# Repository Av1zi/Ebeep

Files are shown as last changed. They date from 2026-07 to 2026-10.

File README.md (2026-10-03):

# Ebeep





Two handheld wireless devices that can message each other and play games, built as a personal gift.

> **E** for eInk. **Beep** for beeper

---

## Project Showcase

### 3d render
https://github.com/user-attachments/assets/a6d2f698-0696-4dca-adf1-06d3810ce39c

### walkthrough
https://github.com/user-attachments/assets/030f00d7-5b2a-4592-a6ae-74eca7de7010

---

## Features

- **Messaging** - 3-button scrollable alphabet, double-space to send
- **Games** - TicTacToe, Connect 4, and Blackjack, all multiplayer over MQTT
- **E-Ink display** - 2.9" screen and low power consumption
- **Battery powered** - LiPo with USB-C charging, percentage always visible
- **Deep sleep** - wakes on a timer or button press to maximise battery life
- **Long range** - talks over WiFi/MQTT, so both devices work from anywhere with an internet connection

---

## Hardware

| Component | Part |
|---|---|
| Microcontroller | Seeed XIAO ESP32-C6 |
| Display | WeAct 2.9" eInk |
| Battery | 3.7V LiPo, 3000mAh |
| Buttons | 3× low profile mechanical keyboard switches |
| Case | ~76g PLA filament <br> 4× M4 heated inserts <br> 4× M4×25 screws |
| Other | 2× 200kΩ resistors (voltage divider for battery sensing) <br> 5×7cm perfboard |

---

## How It Works

### Communication
Both devices connect to WiFi and talk through a private MQTT broker. Each device subscribes to its own topic and publishes to the other's.

### WiFi Setup
On first boot the device creates a hotspot (`Ebeep_1_config` or `Ebeep_2_config`). Connect to it from any phone and a setup page pops up automatically - pick your network, enter the password, done. Credentials are saved to flash and never asked for again unless the connection fails. see walkthrough below:

https://github.com/user-attachments/assets/75ae72dc-5833-4c83-8c6c-1c9a049145ae

### Typing Interface
- **Left / Right** - scroll through characters (`SPC A B C ... Z . ! ? <3`)
- **Select** - confirm the current character
- **Two spaces in a row** - send the message
- **DEL on empty** - exit compose

### Games

- **TicTacToe** - classic 3×3, first message sent starts the match
- **Connect 4** - 7×6 grid, gravity-based drop
- **Blackjack** - single-player, full ruleset with split, double, and a soft-17 dealer

### Power Management
The device spends most of its time in deep sleep, waking every 30 seconds to check for messages. Night hours (00:00–08:00) and low battery stretch that to 2 minutes. Any button press or incoming message triggers a 10-minute active window before it goes back to sleep.

---

## PCB

A custom PCB has been fully designed and routed in KiCad to replace the hand-wired perfboard build. It's not ordered/fabricated yet, so the current build instructions below are still perfboard based (the PCB is a planned upgrade for a future revision.)

> [!WARNING]
> The PCB has not been fitted or tested against the STL case files in this repo. If you order it, expect to redesign the case (or at least the mounting points) to fit. it is **not** a drop-in replacement yet.

---

## Building Your Own

### Electrical Diagram


### Building Instructions
1. 3D print the files from the `CAD` folder
2. Solder everything onto the perfboard following the electrical diagram above
3. Flash the code (see **Setting Up the Code** below) and test before closing the case
4. Fit the components into the case & add double-sided tape under the battery to secure it
5. Press in the 4× M4 heated inserts, then screw the case shut with the M4 screws

### Setting Up the Code
1. Change `DEVICE_NUM` to `1` on one device and `2` on the other
2. Copy `include/secret.example.h` to `include/secret.h` and fill in your MQTT broker credentials (`secret.h` is gitignored so it stays private)
3. Upload via PlatformIO - the `huge_app.csv` partition scheme is required
4. On first boot, connect to the config hotspot (`Ebeep_1_config` or `Ebeep_2_config`) and enter your WiFi credentials

---

## License

GPL 3.0 - Do whatever you want with it, just keep it open source as well.

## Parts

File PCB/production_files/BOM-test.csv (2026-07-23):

Comment | Designator | Footprint | LCSC | Quantity
100nF | C1 | C_0603_1608Metric |  | 1
200K | R1 | R_0603_1608Metric |  | 1
WeAct 2.9" ePaper | Epapers1 | Molex_PicoBlade_53261-0871_1x08-1MP_P1.25mm_Horizontal |  | 1
Conn_01x02 | JST-PH-2pin1 | JST_PH_S2B-PH-K_1x02_P2.00mm_Horizontal |  | 1
100nF | C2 | C_0603_1608Metric |  | 1
200K | R2 | R_0603_1608Metric |  | 1

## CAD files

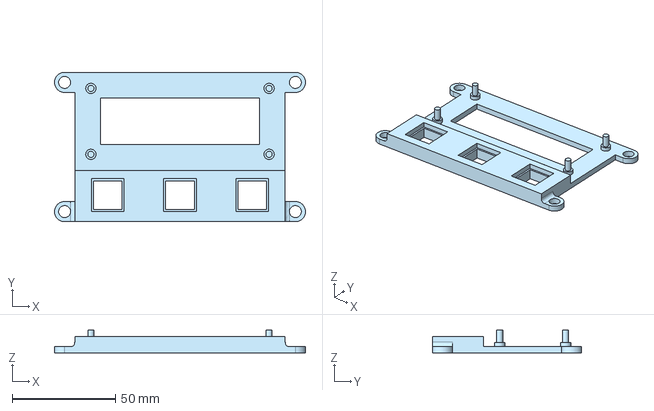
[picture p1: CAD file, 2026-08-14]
CAD/V2 - Top.step
121.4 x 72.3 x 11.0 mm

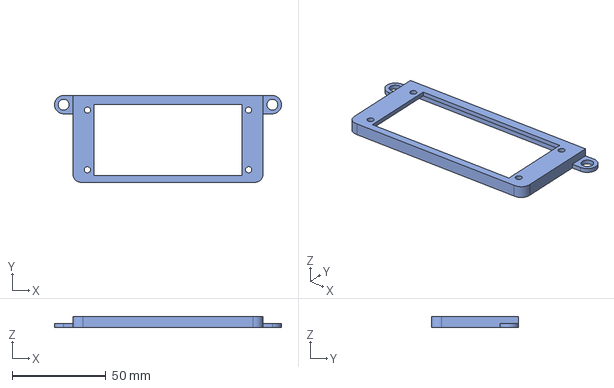
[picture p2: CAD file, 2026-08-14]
CAD/V2 - ScreenCover.step
121.4 x 46.5 x 5.69 mm

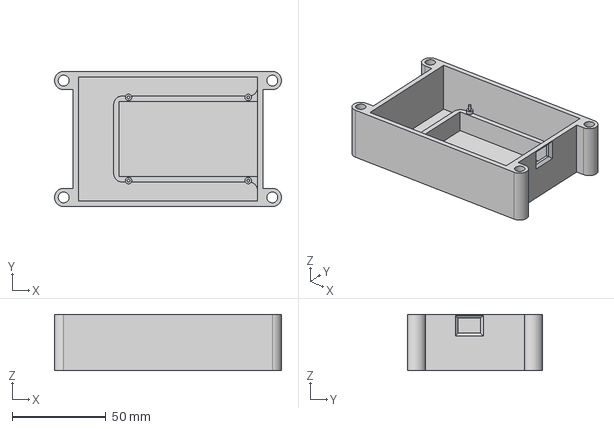
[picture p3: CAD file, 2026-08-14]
CAD/V2 - housing.step
121.4 x 72.3 x 30.0 mm

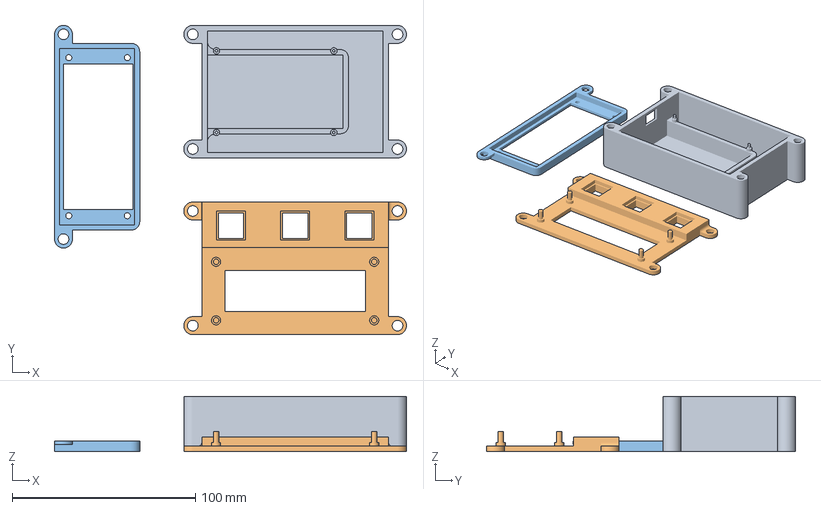
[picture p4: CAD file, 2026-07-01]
CAD/Ebeep V2.3mf
191.9 x 168.6 x 30.0 mm
Ebeep V2 - housing.stl
Ebeep V2 - Top.stl
Ebeep V2 - ScreenCover.stl

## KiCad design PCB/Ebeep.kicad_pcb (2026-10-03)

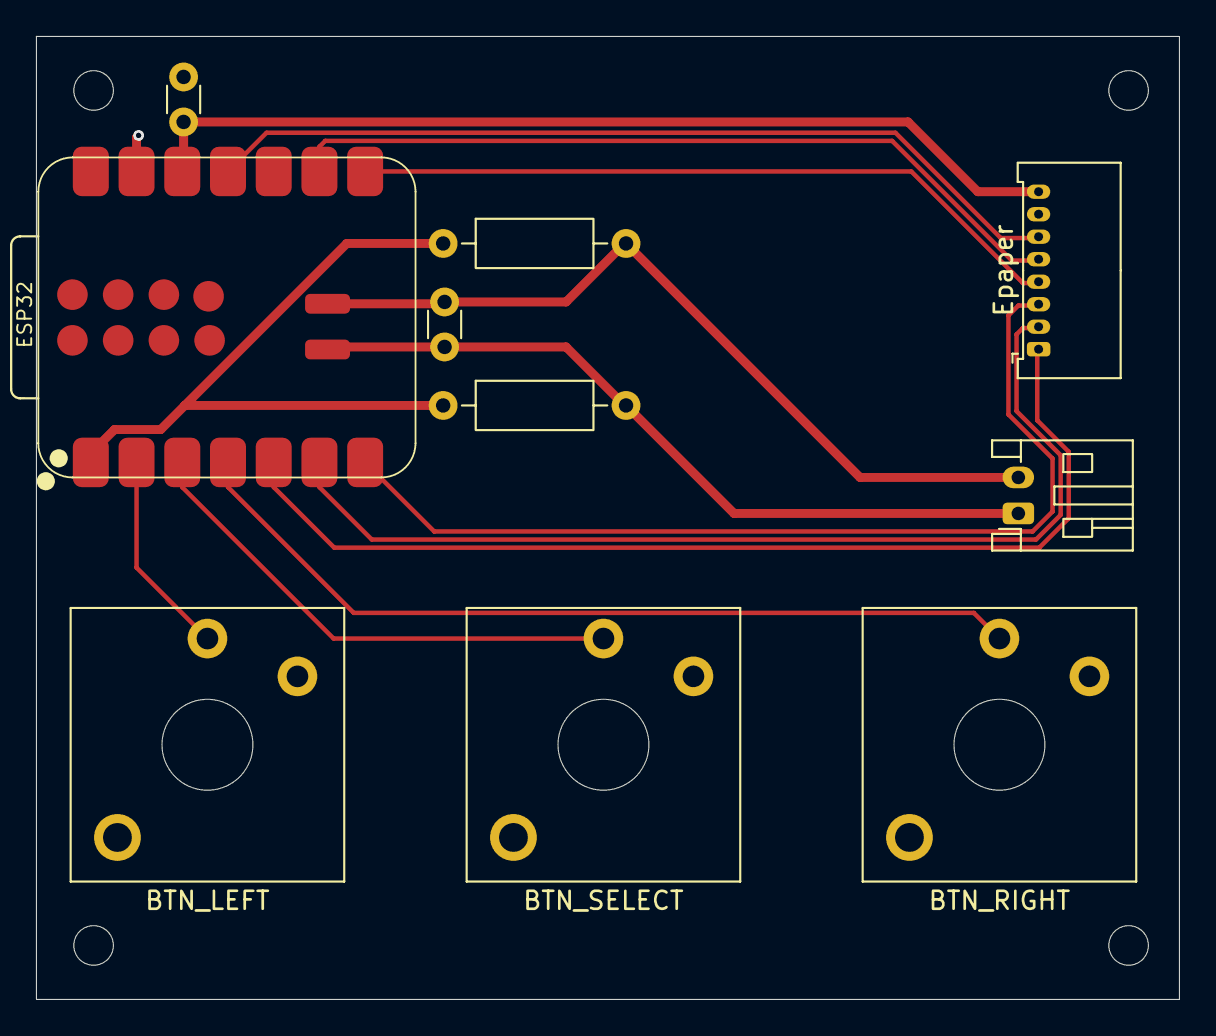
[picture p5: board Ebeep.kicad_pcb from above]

Board: 2 copper layers, 63.5 x 53.5 mm, 10 parts (0 on the bottom side), 14 nets.

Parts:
BTN_LEFT: SW_Push; SW_Kailh_Choc_V2_1.00u
BTN_RIGHT: SW_Push; SW_Kailh_Choc_V2_1.00u
BTN_SELECT: SW_Push; SW_Kailh_Choc_V2_1.00u
C1, C2: 100nF; C_Disc_D3.0mm_W1.6mm_P2.50mm
ESP32: XIAO-ESP32-C6-SMD
Epaper: WeAct 2.9" ePaper; Molex_PicoBlade_53048-0810_1x08_P1.25mm_Horizontal
JST-PH-2pin1: Conn_01x02; JST_PH_S2B-PH-K_1x02_P2.00mm_Horizontal
R1, R2: 200K; R_Axial_DIN0207_L6.3mm_D2.5mm_P10.16mm_Horizontal

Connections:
/+BATT: C1.1, ESP32.23 (VBAT), JST-PH-2pin1.1, R1.2
/-BATT: C1.2, ESP32.24 (GND), JST-PH-2pin1.2, R2.2
/BUSY: ESP32.5 (D4), Epaper.1
/CS: ESP32.8 (D7), Epaper.4
/D/C: ESP32.7 (D6), Epaper.3
/GND: BTN_LEFT.2, BTN_RIGHT.2, BTN_SELECT.2, C2.1, ESP32.13 (GND), Epaper.7
/RES: ESP32.6 (D5), Epaper.2
/SCL: ESP32.9 (D8), Epaper.5
/SDA: ESP32.11 (D10), Epaper.6
/VCC: C2.2, ESP32.12 (3V3_OUT), Epaper.8
unnamed: ESP32.1 (D0), R1.1, R2.1
unnamed: BTN_LEFT.1, ESP32.2 (D1)
unnamed: BTN_SELECT.1, ESP32.3 (D2)
unnamed: BTN_RIGHT.1, ESP32.4 (D3)

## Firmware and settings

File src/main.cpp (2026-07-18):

#include <Arduino.h>
#include <SPI.h>
#include <GxEPD2_BW.h>
#include <Fonts/FreeMonoBold9pt7b.h>
#include <Fonts/FreeMonoBold12pt7b.h>
#include <Fonts/FreeMonoBold24pt7b.h>
#include <WiFiManager.h>
#include <WiFiClientSecure.h>
#include <PubSubClient.h>

#include "config.h"

// ═══════════════════════════════════════════════════════════════
//  CODE INJECTION  (order matters)
// ═══════════════════════════════════════════════════════════════

#include "display_utils.h"
#include "icons.h"
#include "TicTacToeState.h"
#include "Connect4State.h"
#include "BlackjackState.h"
#include "HomeState.h"
#include "InboxState.h"
#include "ComposeState.h"
#include "SentState.h"
#include "GamesState.h"
#include "WifiState.h"
#include "Callbacks.h"

// ═══════════════════════════════════════════════════════════════
//  Functions
// ═══════════════════════════════════════════════════════════════

WiFiManager wm;
unsigned long lastReconnectAttempt = 0;
bool lastWifiState = false;
bool lastMqttState = false;

void connectWifi(){
  wm.setConfigPortalTimeout(0);  // portal never times out
  if (sizeof(HOTSPOT_PASSWORD) > 1) {
    wm.autoConnect(AP_NAME, AP_password);
  } else {
    wm.autoConnect(AP_NAME);
  }
  while (WiFi.status() != WL_CONNECTED) delay(100);
  Serial.println("WiFi connected");
  lastWifiState = true;
}

// build once instead of allocating a String on every single reconnect attempt.
static char INBOX_TOPIC[24] = "";
static char GAMES_TOPIC[24] = "";

bool connectMQTT(){
  if (INBOX_TOPIC[0] == '\0') {
    snprintf(INBOX_TOPIC, sizeof(INBOX_TOPIC), "%s/inbox", BEEPER_ID);
    snprintf(GAMES_TOPIC, sizeof(GAMES_TOPIC), "%s/games", BEEPER_ID);
  }
  Serial.print("MQTT connect... ");
  if (mqttClient.connect(BEEPER_ID, MQTT_USERNAME_STR, MQTT_PASSWORD_STR)) {
    Serial.println("OK");
    mqttClient.subscribe(INBOX_TOPIC);
    mqttClient.subscribe(GAMES_TOPIC);
    lastMqttState = true;
    return true;
  } else {
    Serial.printf("failed rc=%d\n", mqttClient.state());
    return false;
  }
}

// ═══════════════════════════════════════════════════════════════
//  SETUP
// ═══════════════════════════════════════════════════════════════
void setup() {
  Serial.begin(115200);
  delay(2000);
  Serial.println("=== Ebeep Boot ===");
  currentState = STATE_WIFI;
  needRefresh  = true;

  pinMode(EPD_CS,   OUTPUT);
  pinMode(EPD_DC,   OUTPUT);
  pinMode(EPD_RST,  OUTPUT);
  pinMode(EPD_BUSY, INPUT);
  pinMode(BTN_LEFT,   INPUT_PULLUP);
  pinMode(BTN_SELECT, INPUT_PULLUP);
  pinMode(BTN_RIGHT,  INPUT_PULLUP);

  SPI.begin();
  display.init(115200, true, 50, false);
  display.setRotation(3);

  updateBattery();
  mqttClient.setServer(MQTT_SERVER_ADDR, MQTT_SERVER_PORT);
  mqttClient.setCallback(onMessageReceived);


  bool wokeFromTimer = (esp_sleep_get_wakeup_cause() == ESP_SLEEP_WAKEUP_TIMER);
  if (wokeFromTimer && quickCheckAndMaybeSleep()) return;

  // ── WiFi ─────────────────────────────────────────────────
  if (WiFi.status() != WL_CONNECTED) {
    refreshDisplay();   // shows wifisate
    needRefresh = false;
    //wm.resetSettings();  // uncomment to erase save wifi credentials
    connectWifi();
  }
  wifiClient.setInsecure();
  wifiClient.setTimeout(WIFI_CONNECT_TIMEOUT_MS);
  mqttClient.setSocketTimeout(WIFI_CONNECT_TIMEOUT_MS / 1000);
  WiFi.setAutoReconnect(true); // Let hardware handle background wifi reconnection
  WiFi.setSleep(WIFI_PS_MIN_MODEM);

  // ── MQTT ─────────────────────────────────────────────────
  if (!mqttClient.connected()) connectMQTT();
  syncNightClock();  // one-time NTP sync

  currentState = STATE_HOME;
  needRefresh  = true;
  markActivity();
}

// ═══════════════════════════════════════════════════════════════
//  LOOP
// ═══════════════════════════════════════════════════════════════
static unsigned long lastStatusBarRefresh = 0;
static unsigned long lastBatteryRead      = 0;
static unsigned long now;
unsigned long wifiLostAt = 0;

void loop() {
  now = millis();

  checkButtons();

  bool currentWifiState = (WiFi.status() == WL_CONNECTED);
  bool currentMqttState = mqttClient.connected();
  bool iconsStale = (currentWifiState != lastWifiState) || (currentMqttState != lastMqttState);

  if (currentWifiState != lastWifiState) {
    lastWifiState = currentWifiState;
    if (!currentWifiState) wifiLostAt = now;   // outage just started
  }
  lastMqttState = currentMqttState;

  const bool fullyConnected = currentWifiState && currentMqttState;

  if (currentState == STATE_WIFI && fullyConnected) {
    currentState = STATE_HOME;
    needRefresh  = true;
    fastUpdate   = false;
  } else if (currentState != STATE_WIFI && !currentWifiState &&
             now - wifiLostAt > WIFI_RECONNECT_GRACE_MS && !sleepWouldLoseState()) {
    currentState = STATE_WIFI;
    needRefresh  = true;
    fastUpdate   = false;
  }

  if (!currentWifiState) {
    // WiFi is down. Hardware is auto-reconnecting.
  }
  else if (!currentMqttState) {
    if (now - lastReconnectAttempt > 5000) {
      lastReconnectAttempt = now;
      if (connectMQTT()) {
        lastReconnectAttempt = 0;
      }
    }
  }
  else {
    mqttClient.loop();
  }

  if (now - lastBatteryRead > BATTERY_READ_INTERVAL_MS) {
    lastBatteryRead = now;
    updateBattery();
  }

  if (currentState == STATE_SENT && (millis() - sentEnteredAt >= SENT_DISPLAY_MS)) {
    currentState = STATE_HOME;
    needRefresh  = true;
    fastUpdate   = false;
  }

  if (needRefresh) {
    needRefresh = false;
    refreshDisplay();
    lastStatusBarRefresh = now;
  } else if (iconsStale || now - lastStatusBarRefresh > STATUS_REFRESH_MS) {
    lastStatusBarRefresh = now;
    refreshStatusBarOnly();   // icons only — no reason to redraw the whole screen for this
  }

  handlePowerState();
}

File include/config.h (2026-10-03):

#pragma once

#include <secret.h>  // HOTSPOT_PASSWORD, MQTT_SERVER, MQTT_PORT, MQTT_PASSWORD
// not even needed can just write the values directly in config.h, but this keeps them out of git.

// ═══════════════════════════════════════════════════════════════
//  config.h - Hardware pins, layout constants, and app settings.
// ═══════════════════════════════════════════════════════════════

#define EPD_CS    17   // D7
#define EPD_DC    16   // D6
#define EPD_RST   23   // D5
#define EPD_BUSY  22   // D4

// ── Button Pins ───────────────────────────────────────────────
#define BTN_LEFT    1   // D1
#define BTN_SELECT  2   // D2
#define BTN_RIGHT  21   // D3

// ── Display Dimensions (2.9", landscape) ─────────────────────
#define SCREEN_W  296
#define SCREEN_H  128

// ── Vertical Layout ───────────────────────────────────────────
//   y=  0  ╔═══ Status bar ══════════════════════════════════╗
//   y= 22  ╠════════════════════════════════════════════════╣
//   y= 23  ║           CONTENT AREA  (85 px)                ║
//   y=107  ║                                                 ║
//   y=108  ╠════════════════════════════════════════════════╣
//   y=109  ║   [ Left ]      [ Mid ]      [ Right ]   (19px)║
//   y=127  ╚════════════════════════════════════════════════╝
#define DIVIDER_TOP    22
#define CONTENT_Y      23
#define CONTENT_H      85
#define DIVIDER_BOT   108
#define BTN_BAR_Y     109
#define BTN_TEXT_Y    124
#define STATUS_TEXT_Y  17

// ── 3-Button Bar Column Split ────────────────────────────────
#define COL_SPLIT1   (SCREEN_W / 3)
#define COL_SPLIT2   (2 * SCREEN_W / 3)
#define COL1_CX      (COL_SPLIT1 / 2)
#define COL2_CX      (COL_SPLIT1 + (COL_SPLIT2 - COL_SPLIT1) / 2)
#define COL3_CX      (COL_SPLIT2 + (SCREEN_W - COL_SPLIT2) / 2)

// ── Home Screen Tiles (78×60, 16px gap, 15px side margins) ───
#define TILE_W    78
#define TILE_H    60
#define TILE_Y    (CONTENT_Y + (CONTENT_H - TILE_H) / 2)
#define TILE1_X   15
#define TILE2_X   109
#define TILE3_X   203

// ── App Settings ──────────────────────────────────────────────
#define MAX_MSG_LEN      30
#define SENT_DISPLAY_MS  3000UL
#define DEBOUNCE_MS      50
#define HOLD_DELAY_MS    500
#define HOLD_REPEAT_MS   150

// ── Battery Sensing ───────────────────────────────────────────
//   2×200kΩ divider (1:2) on A0
#define BATTERY_DIVIDER_RATIO     2.0f
#define BATTERY_MIN_MV            3000UL   // 0%
#define BATTERY_MAX_MV            4200UL   // 100%
#define BATTERY_READ_INTERVAL_MS  3000UL   // how often we sample the ADC
#define BATTERY_EMA_ALPHA         0.15f

// ── Power Management ──────────────────────────────────────────
//   Active   : awake, WiFi modem-sleep only, for ACTIVE_TIMEOUT_MS
//   Default  : deep sleep, wake every WAKE_INTERVAL_DEFAULT_S.
//   Night    : deep sleep, wake every WAKE_INTERVAL_NIGHT_S
//   Low batt : deep sleep, wake every WAKE_INTERVAL_LOWBATT_S (batt < LOW_BATT_PCT).
#define WAKE_INTERVAL_DEFAULT_S   30UL
#define WAKE_INTERVAL_NIGHT_S     120UL
#define WAKE_INTERVAL_LOWBATT_S   120UL
#define ACTIVE_TIMEOUT_MS         (10UL * 60 * 1000)   // stay awake this long after activity
#define STATUS_REFRESH_MS         (2UL * 60 * 1000)    // battery-only partial refresh cadence
#define LOW_BATT_PCT              10                   // below this: 2min sleep tier + status bar warning
#define NIGHT_START_HOUR          0
#define NIGHT_END_HOUR            8
// Default is Israel (IST/IDT);
#define TZ_STRING                 "IST-2IDT,M3.4.4/26,M10.5.0"
#define WIFI_CONNECT_TIMEOUT_MS   5000UL
#define MQTT_LISTEN_WINDOW_MS     3000UL
 

// ── Device Identity ───────────────────────────────────────────
//  THE ONLY LINE TO CHANGE BETWEEN DEVICES.
#define DEVICE_NUM  1   // 1 or 2

#if DEVICE_NUM == 1
  #define AP_NAME    "Ebeep_1_config"
  constexpr const char* BEEPER_ID  = "Beeper_1";
  constexpr const char* RECIVER_ID = "Beeper_2";
#elif DEVICE_NUM == 2
  #define AP_NAME    "Ebeep_2_config"
  constexpr const char* BEEPER_ID  = "Beeper_2";
  constexpr const char* RECIVER_ID = "Beeper_1";
#else
  #error "DEVICE_NUM must be 1 or 2"
#endif    

// ── WiFi / MQTT ───────────────────────────────────────────────
// most of these are defined in a diffrent file (secret.h), to keep them out of git.
#define WIFI_RECONNECT_GRACE_MS   (10UL * 1000)
#define AP_password HOTSPOT_PASSWORD // AP_password: leave empty to create an open acess point.

// MQTT username matches BEEPER_ID
// Password is shared between both devices for simplicity.
constexpr const char* MQTT_SERVER_ADDR  = MQTT_SERVER;
constexpr uint16_t    MQTT_SERVER_PORT  = MQTT_PORT;
constexpr const char* MQTT_USERNAME_STR = BEEPER_ID;
constexpr const char* MQTT_PASSWORD_STR = MQTT_PASSWORD;


// Defined in main.cpp but declared here so PowerState.h can call them
void connectWifi();
bool connectMQTT();
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

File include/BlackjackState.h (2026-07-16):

#pragma once

// ═══════════════════════════════════════════════════════════════
//  BlackjackState.h
// ═══════════════════════════════════════════════════════════════

// ── Phase ────────────────────────────────────────────────────
enum BjPhase : uint8_t { BJ_BETTING, BJ_PLAYER, BJ_RESULT };
static BjPhase bjPhase = BJ_BETTING;

// ── Balance & bet ────────────────────────────────────────────
static int16_t bjBalance  = 100;
static int16_t bjBet      = 25;    // default = 1/4 of starting balance
static uint8_t bjBetFrac  = 0;     // 0=1/4  1=1/2  2=3/4  3=all-in

// ── Deck ─────────────────────────────────────────────────────
static uint8_t bjDeck[52];
static uint8_t bjDeckTop = 52;

static void bjShuffle() {
  for (uint8_t i = 0; i < 52; i++) bjDeck[i] = i;
  for (uint8_t i = 51; i > 0; i--) {
    uint8_t j = random(i + 1);
    uint8_t t = bjDeck[i]; bjDeck[i] = bjDeck[j]; bjDeck[j] = t;
  }
  bjDeckTop = 0;
}

static uint8_t bjDeal() {
  if (bjDeckTop >= 52) bjShuffle();
  return bjDeck[bjDeckTop++];
}

// ── Hands ────────────────────────────────────────────────────
static uint8_t bjPlayer[2][11];
static uint8_t bjPlayerLen[2];
static uint8_t bjDealer[11];
static uint8_t bjDealerLen;
static bool    bjSplit      = false;
static uint8_t bjActiveHand = 0;

// ── Card math ────────────────────────────────────────────────
static uint8_t bjRank(uint8_t card) { return card % 13; }

static uint8_t bjPoints(uint8_t rank) {
  if (rank == 0)  return 11;
  if (rank >= 10) return 10;
  return rank + 1;
}

static uint8_t bjHandValue(const uint8_t* hand, uint8_t len) {
  uint8_t total = 0, aces = 0;
  for (uint8_t i = 0; i < len; i++) {
    uint8_t p = bjPoints(bjRank(hand[i]));
    total += p;
    if (p == 11) aces++;
  }
  while (total > 21 && aces > 0) { total -= 10; aces--; }
  return total;
}

static bool bjIsSoft(const uint8_t* hand, uint8_t len) {
  uint8_t total = 0, aces = 0;
  for (uint8_t i = 0; i < len; i++) {
    uint8_t p = bjPoints(bjRank(hand[i]));
    total += p;
    if (p == 11) aces++;
  }
  return (aces > 0 && total <= 21);
}

// ── Bet fraction helpers ──────────────────────────────────────
static const char* BJ_FRAC_LABELS[] = { "1/4", "1/2", "3/4", "All" };

static int16_t bjBetFromFrac(uint8_t frac) {
  int16_t b;
  switch (frac) {
    case 0: b = bjBalance / 4;   break;
    case 1: b = bjBalance / 2;   break;
    case 2: b = (bjBalance * 3) / 4; break;
    default: b = bjBalance;      break;
  }
  return max((int16_t)1, b);
}

// ── Action menu ──────────────────────────────────────────────
enum BjAction : uint8_t { BJ_HIT, BJ_STAND, BJ_DOUBLE, BJ_SPLIT, BJ_EXIT, BJ_TEST_MASSIVE };
static uint8_t bjActions[6];
static uint8_t bjActionCount;
static uint8_t bjActionIdx;

static void bjBuildActions() {
  bjActionCount = 0;
  bjActions[bjActionCount++] = BJ_HIT;
  bjActions[bjActionCount++] = BJ_STAND;
  const uint8_t* hand = bjPlayer[bjActiveHand];
  const uint8_t  len  = bjPlayerLen[bjActiveHand];
  if (len == 2 && bjBalance >= bjBet)
    bjActions[bjActionCount++] = BJ_DOUBLE;
  if (!bjSplit && len == 2 && bjRank(hand[0]) == bjRank(hand[1]) && bjBalance >= bjBet)
    bjActions[bjActionCount++] = BJ_SPLIT;
  bjActions[bjActionCount++] = BJ_EXIT;
  bjActionIdx = 0;
}

static const char* bjActionLabel(BjAction a) {
  switch (a) {
    case BJ_HIT:          return "Hit";
    case BJ_STAND:        return "Stand";
    case BJ_DOUBLE:       return "Dbl";
    case BJ_SPLIT:        return "Split";
    case BJ_EXIT:         return "Exit";
    case BJ_TEST_MASSIVE: return "Test11";
    default:              return "?";
  }
}

// ── Result ───────────────────────────────────────────────────
enum BjResult : uint8_t { BJ_R_NONE, BJ_R_WIN, BJ_R_LOSE, BJ_R_PUSH, BJ_R_BLACKJACK };
static BjResult bjResult[2];

static const char* bjResultStr(BjResult r) {
  switch (r) {
    case BJ_R_BLACKJACK: return "Blackjack!";
    case BJ_R_WIN:       return "Win!";
    case BJ_R_LOSE:      return "Lose";
    case BJ_R_PUSH:      return "Push";
    default:             return "";
  }
}

// ── Card drawing ─────────────────────────────────────────────
// Each card: 26px wide, 34px tall
static constexpr int16_t BJ_CW   = 26;
static constexpr int16_t BJ_CH   = 34;
static constexpr int16_t BJ_STEP = 28;  // default step size (guarantees 2px gap)

// Leftmost limits on the screen to prevent cards overlapping text labels
static constexpr int16_t BJ_DEALER_MIN_X = 95;  // Space for "Dealer: XX"
static constexpr int16_t BJ_PLAYER_MIN_X = 75;  // Space for "You: XX" or "H1:XX •"

// Dynamic step logic to contract gaps as hand sizes grow
static int16_t bjGetStep(uint8_t len, int16_t minX) {
  if (len <= 1) return BJ_STEP;
  int16_t maxWidth = (SCREEN_W - 2) - minX;
  int16_t maxStep = (maxWidth - BJ_CW) / (len - 1);
  if (maxStep > BJ_STEP) return BJ_STEP;
  if (maxStep < 4) return 4; // Absolute minimum floor so cards are readable
  return maxStep;
}

static void bjDrawCard(int16_t x, int16_t y, uint8_t card, bool hidden) {
  display.fillRect(x, y, BJ_CW, BJ_CH, GxEPD_WHITE);
  display.drawRect(x, y, BJ_CW, BJ_CH, GxEPD_BLACK);
  
  if (hidden) {
    for (int16_t dy = 3; dy < BJ_CH - 2; dy += 3)
      display.drawFastHLine(x + 2, y + dy, BJ_CW - 4, GxEPD_BLACK);
    return;
  }
  
  char rb[3];
  uint8_t rank = bjRank(card);
  if (rank == 9) {
    snprintf(rb, sizeof(rb), "10");
  } else if (rank < 9) {
    snprintf(rb, sizeof(rb), "%c", "A23456789"[rank]);
  } else {
    snprintf(rb, sizeof(rb), "%c", "JQK"[rank - 10]);
  }

  static const char SUITS[] = "SHDC";
  char sb[2] = { SUITS[card / 13], '\0' };
  
  int16_t rankX = (rank == 9) ? x + 1 : x + 4;
  
  drawText(rankX, y + 14, rb, &FreeMonoBold9pt7b);
  drawText(x + 5, y + 30, sb, &FreeMonoBold9pt7b);
}

static void bjDrawHand(int16_t x, int16_t y,
                       const uint8_t* hand, uint8_t len, bool hideSecond, int16_t step) {
  for (uint8_t i = 0; i < len; i++)
    bjDrawCard(x + i * step, y, hand[i], hideSecond && i == 1);
}

// ── Layout constants (absolute y) ────────────────────────────
static constexpr int16_t BJ_CARDS_X        = 96;               
static constexpr int16_t BJ_DEALER_LABEL_Y = CONTENT_Y + 14;   
static constexpr int16_t BJ_DEALER_CARD_Y  = CONTENT_Y +  0;   
static constexpr int16_t BJ_DIVIDER_Y      = CONTENT_Y + 37;   
static constexpr int16_t BJ_PLAYER_LABEL_Y = CONTENT_Y + 52;   
static constexpr int16_t BJ_PLAYER_CARD_Y  = CONTENT_Y + 40;   
static constexpr int16_t BJ_RESULT_Y       = CONTENT_Y + 77;
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

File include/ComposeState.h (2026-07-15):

#pragma once

// ═══════════════════════════════════════════════════════════════
//  ComposeState.h
//
//  Layout (content area y=23..107):
//    y≈51  typed text + cursor underline
//    y≈35  progress bar (fills as you type, inverts at limit)
//    y≈90  < [ selected char ] >  selector
//
//  Double-space to send. DEL on empty → leave-confirm popup.
//  At MAX_MSG_LEN: only DEL and double-space (send) work.
// ═══════════════════════════════════════════════════════════════

static const char ALPHABET[] PROGMEM = " ABCDEFGHIJKLMNOPQRSTUVWXYZ.!?<3";
static const uint8_t ALPHABET_SIZE   = sizeof(ALPHABET) - 1;  // excludes '\0'
static const uint8_t DEL_IDX         = ALPHABET_SIZE;

// ─────────────────────────────────────────────────────────────
void drawCompose() {

  // ── Leave-confirm popup ───────────────────────────────────
if (confirmLeaveCompose) {
    drawConfirmPopup("Quit writing?");
    return;
  }

  // ── Typed text with scrolling cursor ─────────────────────
  // Max 22 chars shown; older characters scroll off the left.
  char textBuf[28];
  if (messageLen == 0) {
    textBuf[0] = '_'; textBuf[1] = '\0';
  } else if (messageLen <= 22) {
    snprintf(textBuf, sizeof(textBuf), "%s_", typedMessage);
  } else {
    snprintf(textBuf, sizeof(textBuf), "...%.19s_", typedMessage + messageLen - 19);
  }
  drawCenteredText(SCREEN_W / 2, CONTENT_Y + 28, textBuf, &FreeMonoBold9pt7b);

  // ── Progress bar ──────────────────────────────────────────
  constexpr int16_t barX = 8;
  constexpr int16_t barY = CONTENT_Y + 35;
  constexpr int16_t barW = SCREEN_W - 16;
  constexpr int16_t barH = 5;

  const bool atLimit = (messageLen >= MAX_MSG_LEN);
  const int16_t fillW = atLimit ? barW : (int16_t)((messageLen * barW) / MAX_MSG_LEN);

  if (atLimit) {
    // Fully filled + invert to make it obvious
    display.fillRect(barX, barY, barW, barH, GxEPD_BLACK);
  } else {
    display.drawRect(barX, barY, barW, barH, GxEPD_BLACK);
    if (fillW > 0) display.fillRect(barX, barY, fillW, barH, GxEPD_BLACK);
  }

  // ── Letter selector ───────────────────────────────────────
  constexpr int16_t selCX = SCREEN_W / 2;
  constexpr int16_t selCY = CONTENT_Y + 67;

  display.drawRect(selCX - 22, selCY - 16, 44, 32, GxEPD_BLACK);

  const char ch = (char)pgm_read_byte(&ALPHABET[currentLetterIdx]);
  if (currentLetterIdx == DEL_IDX) {
    drawCenteredText(selCX, selCY + 5, "DEL", &FreeMonoBold9pt7b);
  } else if (ch == ' ') {
    drawCenteredText(selCX, selCY + 5, "SPC", &FreeMonoBold9pt7b);
  } else {
    char charBuf[2] = { ch, '\0' };
    drawCenteredText(selCX, selCY + 9, charBuf, &FreeMonoBold12pt7b);
  }

  drawCenteredText(selCX - 58, selCY + 9, "<", &FreeMonoBold12pt7b);
  drawCenteredText(selCX + 58, selCY + 9, ">", &FreeMonoBold12pt7b);

  drawButtonHints("<", "OK", ">");
}


// ─────────────────────────────────────────────────────────────
void handleComposeInput(bool leftPressed, bool midPressed, bool rightPressed) {

  // ── Leave-confirm popup ───────────────────────────────────
  if (confirmLeaveCompose) {
    if (leftPressed) {
      confirmLeaveCompose = false;
      needRefresh = true;
      fastUpdate  = true;
    } else if (rightPressed) {
      confirmLeaveCompose = false;
      currentState = STATE_HOME;
      needRefresh  = true;
      fastUpdate   = false;
    }
    return;
  }

  // ── Scroll letter selector ────────────────────────────────
  if (leftPressed) {
    currentLetterIdx = (currentLetterIdx == 0) ? DEL_IDX : currentLetterIdx - 1;
    needRefresh = true;
    fastUpdate  = true;
  } else if (rightPressed) {
    currentLetterIdx = (currentLetterIdx >= DEL_IDX) ? 0 : currentLetterIdx + 1;
    needRefresh = true;
    fastUpdate  = true;

  // ── Confirm / backspace ───────────────────────────────────
  } else if (midPressed) {
    if (currentLetterIdx == DEL_IDX) {
      if (messageLen > 0) {
        typedMessage[--messageLen] = '\0';
        needRefresh = true;
        fastUpdate  = true;
      } else {
        confirmLeaveCompose = true;
        needRefresh = true;
        fastUpdate  = false;
      }
    } else {
      const char ch = (char)pgm_read_byte(&ALPHABET[currentLetterIdx]);

      // Double-space = send (allowed even at limit last char must already be space)
      if (ch == ' ' && messageLen > 0 && typedMessage[messageLen - 1] == ' ') {
        typedMessage[--messageLen] = '\0';   // strip trailing space
        static char inboxTopic[24] = "";     // built once — RECIVER_ID never changes
        if (inboxTopic[0] == '\0') snprintf(inboxTopic, sizeof(inboxTopic), "%s/inbox", RECIVER_ID);
        mqttClient.publish(inboxTopic, typedMessage, true);
        currentState  = STATE_SENT;
        sentEnteredAt = millis();
        needRefresh   = true;
        fastUpdate    = false;
      } else if (messageLen >= MAX_MSG_LEN) {
        // At limit - only DEL and send work. ignore everything else.
        return;
      } else {
        typedMessage[messageLen++] = ch;
        typedMessage[messageLen]   = '\0';
        needRefresh = true;
        fastUpdate  = true;
      }
    }
  }
}

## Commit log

2026-06-09 updated to esp32
2026-06-10 added wifi support and fixed a couple of bugs
    [config.h, main.cpp]
2026-06-19 tic tac toe major overhall
    added a lot of shit as well fixed bugs and tried to make compase state better
    [Callbacks.h, ComposeState.h, config.h]
2026-06-20 added wifi icons and cad files to project
    + fixed bugs
    [Ebeep.3mf, EbeepBOX.stl, EbeepScreenCover.stl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]
2026-06-21 tic tac toe working
    updated model for M4 screws
    [Ebeep.3mf, EbeepBOX.stl, EbeepScreenCover.stl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]
2026-07-01 Updated STLs
    [Ebeep V2 - housing.stl, Ebeep V2 - ScreenCover.stl, Ebeep V2 - Top.stl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]
2026-07-01 battery management?
2026-07-02 made the buttons actually wake up the device
2026-07-05 fix sleep thing? maybe hopefully?
    [Callbacks.h, config.h, main.cpp]
2026-07-06 Fixed wifi bug and updated the readme file
    i think its fixed i really hope so
    [Callbacks.h, ComposeState.h, config.h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]
2026-07-14 black jack + bug fix
    now the portal doesnt time out
    [BlackjackState.h, Callbacks.h, config.h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]
2026-07-16 fixed a bug with bj and made split work better
    [BlackjackState.h]
2026-07-18 removed un nessesery files and fixed a bug with mqtt
    [Callbacks.h, config.h, main.cpp]
2026-08-14 converted files to .step
    [Ebeep V2 - ScreenCover.stl, Ebeep V2 - Top.stl, Ebeep V2 - housing.stl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]
2026-10-03 KiCad Files
    [Ebeep.kicad_pcb, Ebeep.kicad_sch]
2026-10-20 update powerdraw
2026-10-21 maybe power draw will be better thanks claude
2026-10-23 added a photo of the PCB
2026-10-23 fix power
2026-10-23 Fix self-waking deep sleep, keep awake while busy, split up Callbacks.h
    - Wake buttons use GPIO wakeup instead of ext1. On this board ext1 pulled
    the chip back out of deep sleep ~70 ms later with no wake cause, so it
    never actually slept.
    - Don't sleep while writing a message or in any game (Blackjack included),
    unless left untouched for 15 minutes.
    - Split Callbacks.h into Callbacks.h (buttons, display, MQTT messages),
    Connection.h (WiFi networks, setup hotspot, MQTT) and Power.h (battery,
    sleep). One dispatchInput() replaces three copies of the input switch.
    - Boot log line says why the device reset / woke up.
2026-10-23 Cap TLS handshake at 8 s, keep radio awake during MQTT connect, log slow loops
    A stalled MQTT/TLS handshake could block loop() for up to 120 s (the
    library default), dropping button presses and screen refreshes.
2026-10-23 Stop USB serial prints from freezing the beeper
    Plugged into a PC with no serial monitor open, nothing reads the USB
    CDC output, so every print blocked up to 2 s. GxEPD2's per-refresh
    timing prints alone stacked that into minute-long freezes; opening a
    monitor or flashing drained the buffer and made it go away.
2026-10-23 Fix Sent! screen being skipped after sending
    The timeout check compared against `now`, taken before checkButtons()
    set sentEnteredAt, so the unsigned subtraction wrapped and the screen
    returned home instantly. Use millis() again.
2026-11-01 move STL and STEP file to thier on sub folder
